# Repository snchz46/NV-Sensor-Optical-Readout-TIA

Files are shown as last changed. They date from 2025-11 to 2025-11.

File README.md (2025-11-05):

# NV-Sensor-Optical-Readout-TIA

Development of an optical NV-diamond fluorescence sensing platform using a BPW34 photodiode and MCP607 transimpedance amplifier (TIA), read out by either the ESP32 internal ADC or an external 16-bit ADS1115.

## System Overview
- Photodiode: BPW34 reverse-biased
- Op-Amp: MCP607, low-noise rail-to-rail
- ADC: ADS1115 via I²C (16-bit) and ESP32 internal (12-bit)
- Magnetic field applied via adjustable neodymium magnet (threaded rod system)
- Output signal measured as fluorescence intensity quenching under magnetic field

## Hardware
Rf/Cf tuning for gain–bandwidth tradeoff:
| Rf (Ω) | Cf (F) | Cutoff (Hz) |
|---|---|---|
| 1MΩ | 3.3pF | 48kHz |
| 470kΩ | 10nF | 34Hz |
| 220kΩ | 10nF | 72Hz |

## Firmware
Includes:
- ESP32 ADC test firmware (analogRead averaging, exponential filter)
- ADS1115 readout firmware (noise RMS calculation, CSV logging)
- Real-time noise comparison (ESP32 vs ADS1115)

## Data & Analysis
- Data stored as CSV under `/data/`
- Python scripts for plotting and computing noise, SNR, and ΔI/I vs magnetic field
- Lock-in analysis planned for modulated field measurements

## Example Results
| Parameter | ESP32 ADC | ADS1115 |
|---|---|---|
| Resolution | 12-bit | 16-bit |
| RMS Noise | ~6.6 mV | ~0.34 mV |
| SNR | – | +26 dB |
| Range | 0–2.6 V | 0–4.1 V |

## Roadmap
- [ ] Implement software lock-in detection
- [ ] Integrate higher-resolution ADC (ADS131M04)
- [ ] Design modular PCB with adjustable feedback network
- [ ] Add ROS2 node for remote NV-sensor readout

## Author
Samuel Sánchez Moreno  
Fraunhofer IAO Project

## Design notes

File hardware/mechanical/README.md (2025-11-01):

# Optical Alignment Notes

The mechanical fixtures in this directory focus on aligning the LED excitation source, NV-diamond sample, and BPW34 photodiode so that fluorescence changes translate into reliable photocurrent.

## Alignment Strategy
- **LED Mount:** Collimated green LED source mounted on a threaded holder for focus adjustment.
- **Diamond Seat:** 3D-printed saddle that locks the NV-diamond at the beam waist while keeping optical epoxy clear of the sensor area.
- **Photodiode Bracket:** Adjustable arm that places the BPW34 at 90° to the excitation path to minimise stray reflections.

## Magnetic Field Integration
- Threaded rod guides a neodymium magnet to vary the local magnetic field strength.
- Scale markings along the rod translate position to approximate magnetic flux density.

Document STL revisions and alignment measurements inside this folder to streamline experimental replication.

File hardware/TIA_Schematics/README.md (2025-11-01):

# MCP607 TIA Schematic Notes

This folder hosts the schematic sources for the MCP607-based transimpedance amplifier that converts the BPW34 photodiode current into a measurable voltage for both ESP32 and ADS1115 data acquisition paths.

## Core Circuit Blocks
- **Photodiode stage:** BPW34 reverse biased at 5 V to reduce junction capacitance and improve linearity.
- **Transimpedance amplifier:** MCP607 configured in inverting mode with low-noise feedback network and guard ring routing recommendations.
- **Filter options:** Optional RC snubber and differential output driver footprints for shielded cable runs.

## Feedback Network Tuning
The effective gain and bandwidth are determined by the feedback components:
- **Rf:** Sets the transimpedance gain (V/A). Typical values from 220 kΩ to 1 MΩ.
- **Cf:** Stabilises the op-amp and introduces a pole to limit noise. Typical values from 3.3 pF to 10 nF depending on Rf and cable capacitance.
- Combine Rf and Cf according to the target cutoff frequency listed in the project README.

## Simulation Guidance
- Use LTspice, TI-TINA, or KiCad Ngspice with the MCP607 macro-model for stability analysis.
- Sweep input capacitance (photodiode + wiring) between 50 pF and 200 pF.
- Validate phase margin >45° for all operating points and check output swing versus expected photocurrent.

Document simulation results under `data/tia_rf_cf_sweep/` to maintain traceability between design and measurement.

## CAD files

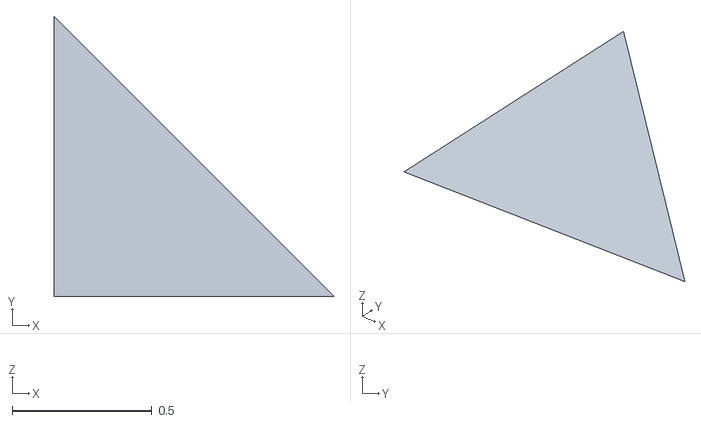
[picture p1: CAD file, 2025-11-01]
hardware/mechanical/NV_Holder_3D_Design_placeholder.stl
1.00 x 1.00 x 0

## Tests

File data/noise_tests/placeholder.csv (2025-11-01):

sample | voltage_rms
0 | 0.000

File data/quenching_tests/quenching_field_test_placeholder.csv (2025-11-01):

field_mT | delta_I_over_I
0 | 0.0

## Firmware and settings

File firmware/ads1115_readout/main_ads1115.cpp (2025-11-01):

#include <Arduino.h>
#include <Wire.h>
#include <Adafruit_ADS1X15.h>

Adafruit_ADS1115 ads;

constexpr uint8_t kChannel = 0;
constexpr size_t kWindow = 128;
constexpr float kFullScaleVoltage = 4.096f;  // Gain = 1
constexpr float kLsb = kFullScaleVoltage / 32768.0f;

float samples[kWindow];
size_t sampleIndex = 0;
bool bufferFilled = false;

float computeMean() {
  size_t count = bufferFilled ? kWindow : sampleIndex;
  if (count == 0) {
    return 0.0f;
  }
  float sum = 0.0f;
  for (size_t i = 0; i < count; ++i) {
    sum += samples[i];
  }
  return sum / static_cast<float>(count);
}

float computeRms(float mean) {
  size_t count = bufferFilled ? kWindow : sampleIndex;
  if (count == 0) {
    return 0.0f;
  }
  float accum = 0.0f;
  for (size_t i = 0; i < count; ++i) {
    float diff = samples[i] - mean;
    accum += diff * diff;
  }
  return sqrtf(accum / static_cast<float>(count));
}

void setup() {
  Serial.begin(115200);
  delay(500);
  Wire.begin();

  if (!ads.begin()) {
    Serial.println("Error: Failed to initialise ADS1115");
    while (true) {
      delay(1000);
    }
  }

  ads.setGain(GAIN_ONE);  // ±4.096 V range
  ads.setDataRate(RATE_ADS1115_860SPS);

  Serial.println("sample,timestamp_us,voltage_mean,voltage_rms,buffer_count");
}

void loop() {
  int16_t raw = ads.readADC_SingleEnded(kChannel);
  float voltage = raw * kLsb;

  samples[sampleIndex] = voltage;
  sampleIndex = (sampleIndex + 1) % kWindow;
  if (sampleIndex == 0) {
    bufferFilled = true;
  }

  float mean = computeMean();
  float rmsNoise = computeRms(mean);

  static uint32_t recordIndex = 0;
  Serial.print(recordIndex++);
  Serial.print(',');
  Serial.print(micros());
  Serial.print(',');
  Serial.print(mean, 6);
  Serial.print(',');
  Serial.print(rmsNoise, 6);
  Serial.print(',');
  Serial.println(bufferFilled ? kWindow : sampleIndex);

  delay(50);
}

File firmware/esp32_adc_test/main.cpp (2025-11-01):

#include <Arduino.h>

constexpr uint8_t kAdcPin = 34;      // GPIO34 is input only on ESP32
constexpr size_t kSamplesPerBatch = 64;
constexpr uint32_t kSampleDelayUs = 200;  // 5 kHz sample rate target
constexpr float kEmaAlpha = 0.1f;

float emaValue = 0.0f;

void setup() {
  Serial.begin(115200);
  delay(500);
  analogReadResolution(12);
  analogSetPinAttenuation(kAdcPin, ADC_11db);
  emaValue = analogRead(kAdcPin);
  Serial.println("sample,timestamp_us,adc_raw,adc_avg,ema_filtered");
}

void loop() {
  uint32_t batchStartMicros = micros();
  uint32_t sum = 0;
  for (size_t i = 0; i < kSamplesPerBatch; ++i) {
    uint32_t value = analogRead(kAdcPin);
    sum += value;
    delayMicroseconds(kSampleDelayUs);
  }

  float avg = static_cast<float>(sum) / static_cast<float>(kSamplesPerBatch);
  emaValue = kEmaAlpha * avg + (1.0f - kEmaAlpha) * emaValue;

  static uint32_t sampleIndex = 0;
  uint32_t timestamp = micros();
  Serial.print(sampleIndex++);
  Serial.print(',');
  Serial.print(timestamp);
  Serial.print(',');
  Serial.print(sum / kSamplesPerBatch);
  Serial.print(',');
  Serial.print(avg, 4);
  Serial.print(',');
  Serial.println(emaValue, 4);

  // Maintain approximate loop rate of ~20 Hz for CSV logging.
  uint32_t loopDuration = micros() - batchStartMicros;
  if (loopDuration < 50000) {
    delayMicroseconds(50000 - loopDuration);
  }
}
